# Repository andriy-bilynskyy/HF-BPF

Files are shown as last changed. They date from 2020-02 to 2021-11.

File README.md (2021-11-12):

# Short wave BPF

This is HW design of passive shortwave BPF 1.8MHz - 30MHz.

The schematic is based on 1.8MHz 7-th order elliptic HPF and 30MHz 7-th order elliptic LPF.

Input output filter resistance is 50 Ohms.

Loses in band-pass are less than -6.8dB. Loses at 60MHz and more are more than -80 dB. The same situation for frequencies lower than  1MHz - -80dB.

The design is created to use together with SDR receivers due to problematic reception of shot-wave bands in city conditions. This situation is mainly caused by huge noise from different switch power converters/inverters at low frequencies and FM radios at high frequencies.

## Folder structure

- **HF-BPF.asc** - LTspice simulation.  https://www.analog.com/en/design-center/design-tools-and-calculators/ltspice-simulator.html

- **HF-BPF.pro** - KiCad project. https://kicad.org/

- **HF-BPF.sch** - KiCad schematic.

- **HF-BPF.kicad_pcb** - KiCad PCB.

- **HF-BPF.net** - KiCad net-list file.

- **Manufacture** - Gerber files for PCB manufacturing. PCB manufacture https://www.elecrow.com/pcb-manufacturing.html

# Amplitude-frequency characteristic
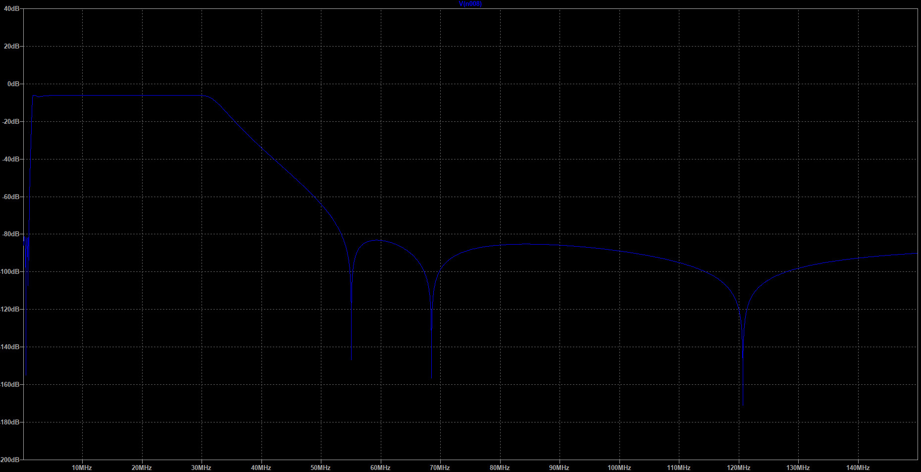
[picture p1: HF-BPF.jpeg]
Amplitude-frequency characteristic


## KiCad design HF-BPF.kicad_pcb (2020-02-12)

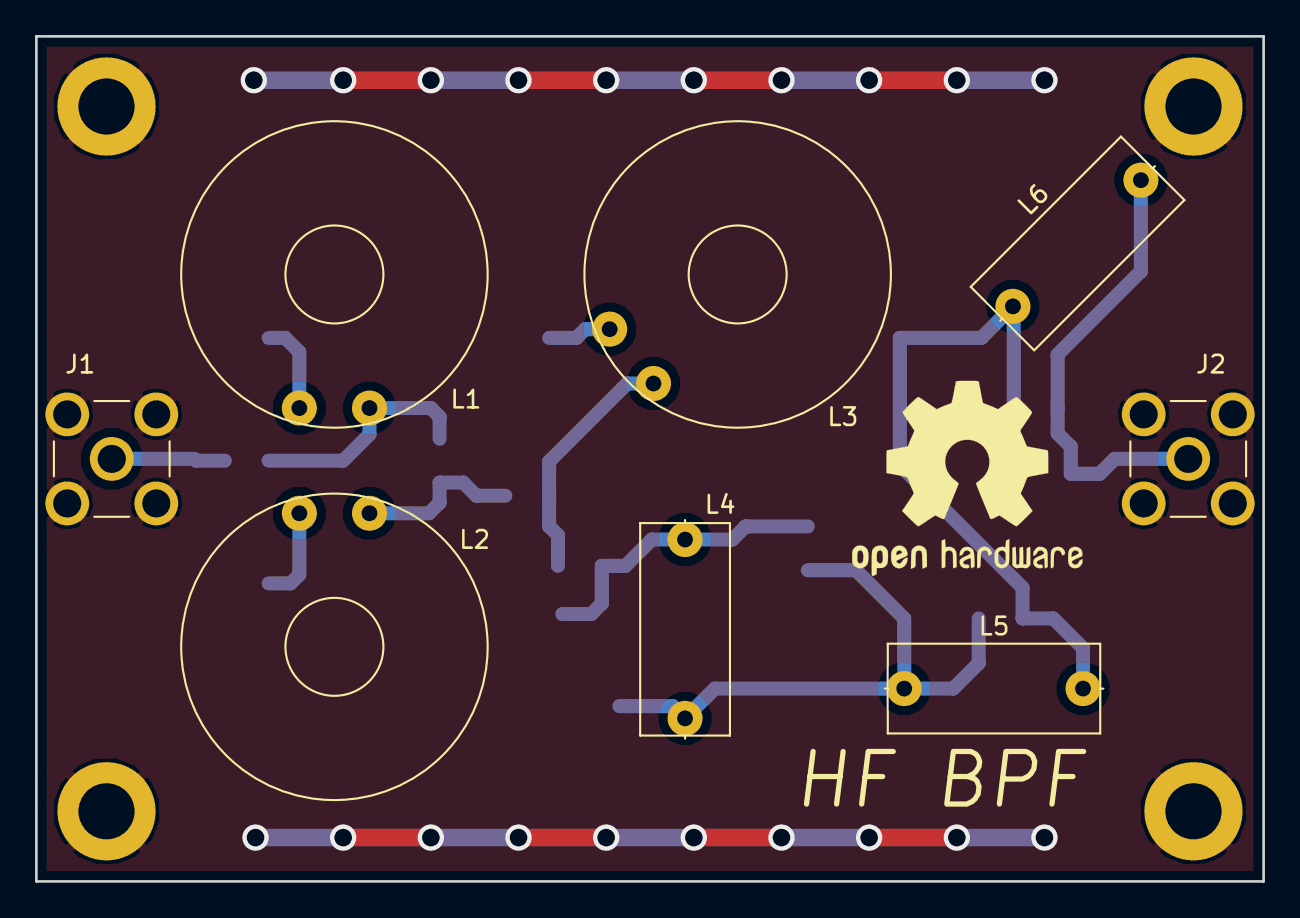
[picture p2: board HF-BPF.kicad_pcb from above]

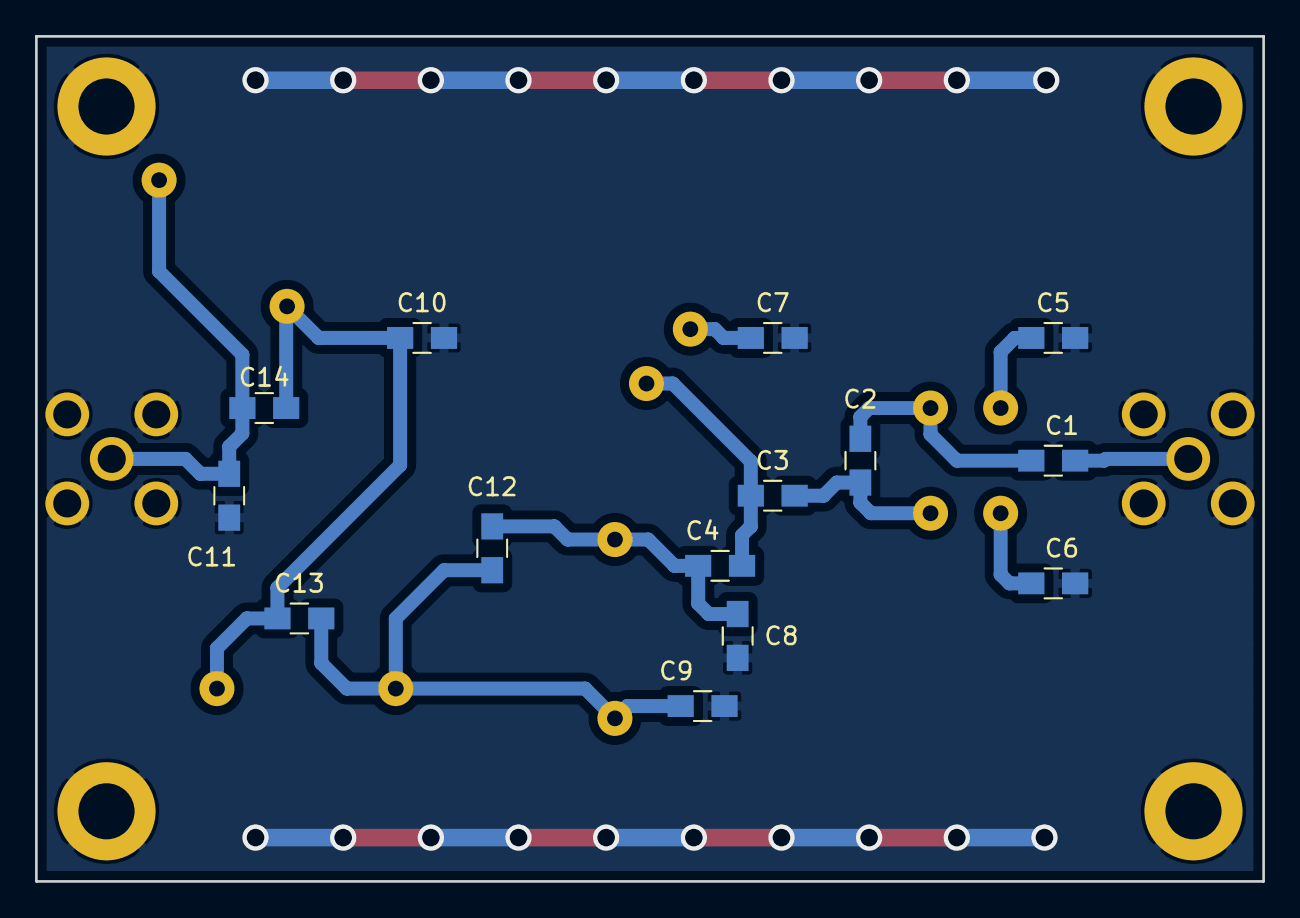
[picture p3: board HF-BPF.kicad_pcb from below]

Board: 2 copper layers, 70.0 x 48.2 mm, 22 parts (14 on the bottom side), 12 nets.

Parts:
C1, C4: 2.2nF; C_0805_HandSoldering
C2, C3: 1.5nF; C_0805_HandSoldering
C5: 33nF; C_0805_HandSoldering
C6, C7: 10nF; C_0805_HandSoldering
C8: 82pF; C_0805_HandSoldering
C9: 180pF; C_0805_HandSoldering
C10: 150pF; C_0805_HandSoldering
C11: 68pF; C_0805_HandSoldering
C12: 4.7pF; C_0805_HandSoldering
C13: 22pF; C_0805_HandSoldering
C14: 15pF; C_0805_HandSoldering
J1, J2: SMA-15; SMA_THT_Jack_Straight
L1: 3.2uH; L_Toroid_Horizontal_D17.3mm_P15.24mm_Bourns_2000
L2: 2.5uH; L_Toroid_Horizontal_D17.3mm_P15.24mm_Bourns_2000
L3: 3.6uH; L_Toroid_Horizontal_D17.3mm_P15.24mm_Bourns_2000
L4: 370nH; L_Axial_L12.0mm_D5.0mm_P15.24mm_Horizontal_Fastron_MISC
L5: 380nH; L_Axial_L12.0mm_D5.0mm_P15.24mm_Horizontal_Fastron_MISC
L6: 360nH; L_Axial_L12.0mm_D5.0mm_P15.24mm_Horizontal_Fastron_MISC

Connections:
GND: C5.1, C6.1, C7.1, C8.1, C9.1, C10.1, C11.1, J1.2, J2.2
unnamed: C1.1, C2.2, L1.1
unnamed: C1.2, J1.1
unnamed: C2.1, C3.2, L2.1
unnamed: C3.1, C4.2, L3.1
unnamed: C5.2, L1.2
unnamed: C6.2, L2.2
unnamed: C7.2, L3.2
unnamed: C10.2, C13.1, C14.2, L5.2, L6.1
unnamed: C11.2, C14.1, J2.1, L6.2
unnamed: C9.2, C12.1, C13.2, L4.2, L5.1
unnamed: C4.1, C8.2, C12.2, L4.1

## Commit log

2020-02-12 Add PCB artwork.
    [HF-BPF.kicad_pcb, HF-BPF.sch]
2020-02-13 Add manufacture files.
    [HF-BPF.GBL, HF-BPF.GBO, HF-BPF.GBS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]
2020-03-08 Update to kicad 5.
    [HF-BPF.sch]
